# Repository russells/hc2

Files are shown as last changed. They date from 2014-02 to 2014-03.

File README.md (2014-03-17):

# "Hots and Colds thermometer."

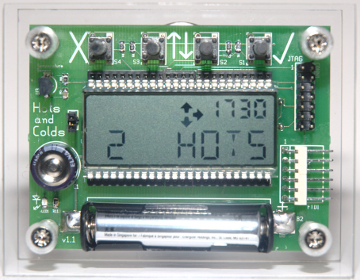
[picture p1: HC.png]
HC


Displays temperature as

 * 20C = "NORMAL"
 * < 20C = "NN COLDS", where NN = 20-T
 * \> 20C = "NN HOTS", where NN = T-20

A wedding present for Andrew and Kate.

# Hardware

## Microcontroller

 * MSP430F449IPZ.
 * Has a builtin LCD controller.
 * http://www.ti.com/product/msp430f449
 * Available from RS.

## Display

### SoftBaugh SBLCDA2

 * Has many display components
    * 14 segment starburst, 7 digits, with 6 decimal points.
    * 7 segment, 4 digits, with 3 decimal points, and colon.
    * Battery meter.
    * Progress bar.
    * Antenna and 3 part signal strength meter.
    * Plus and minus signs.
    * 4 arrow signs.
 * Because of the extra components, more than just having a set of 7 or 14
   segment characters, we can implement a clock and a menu system.
 * Available from http://microcontrollershop.com/

## Temperature sensor

 * MCP9700A
    * Analogue output
    * Vcc down to 2.3V

## Board

 * Made at PCB Zone, http://pcbzone.net/

# Power

 * 2 x AAA cells.

## Power measurements

 * With serial and LED disabled, power consumption has been measured at
   25.8uA mean.
    * 13uA background
    * 60uA, 50us pulses, 3.9ms apart - this is the LCD clock.
    * 430uA, 170 us pulses, at 32Hz (31250us period) - this is the timer
      tick with short periods of 1MHz clock.
    * 510uA, 38ms pulses, at 0.5Hz (2000ms period) - this is the ADC being
      read every two seconds, along with the extra CPU and 1MHz clock
      activity.
    * Total power = 13 + 60\*(50/3900) + 430\*(170/31250) + 510\*(38/2000)
      = 25.8uA
 * With the batteries at 2.9V, one battery was removed.  The unit ran for
   30 minutes, with the capacitor supply voltage dropping to 2.25V.

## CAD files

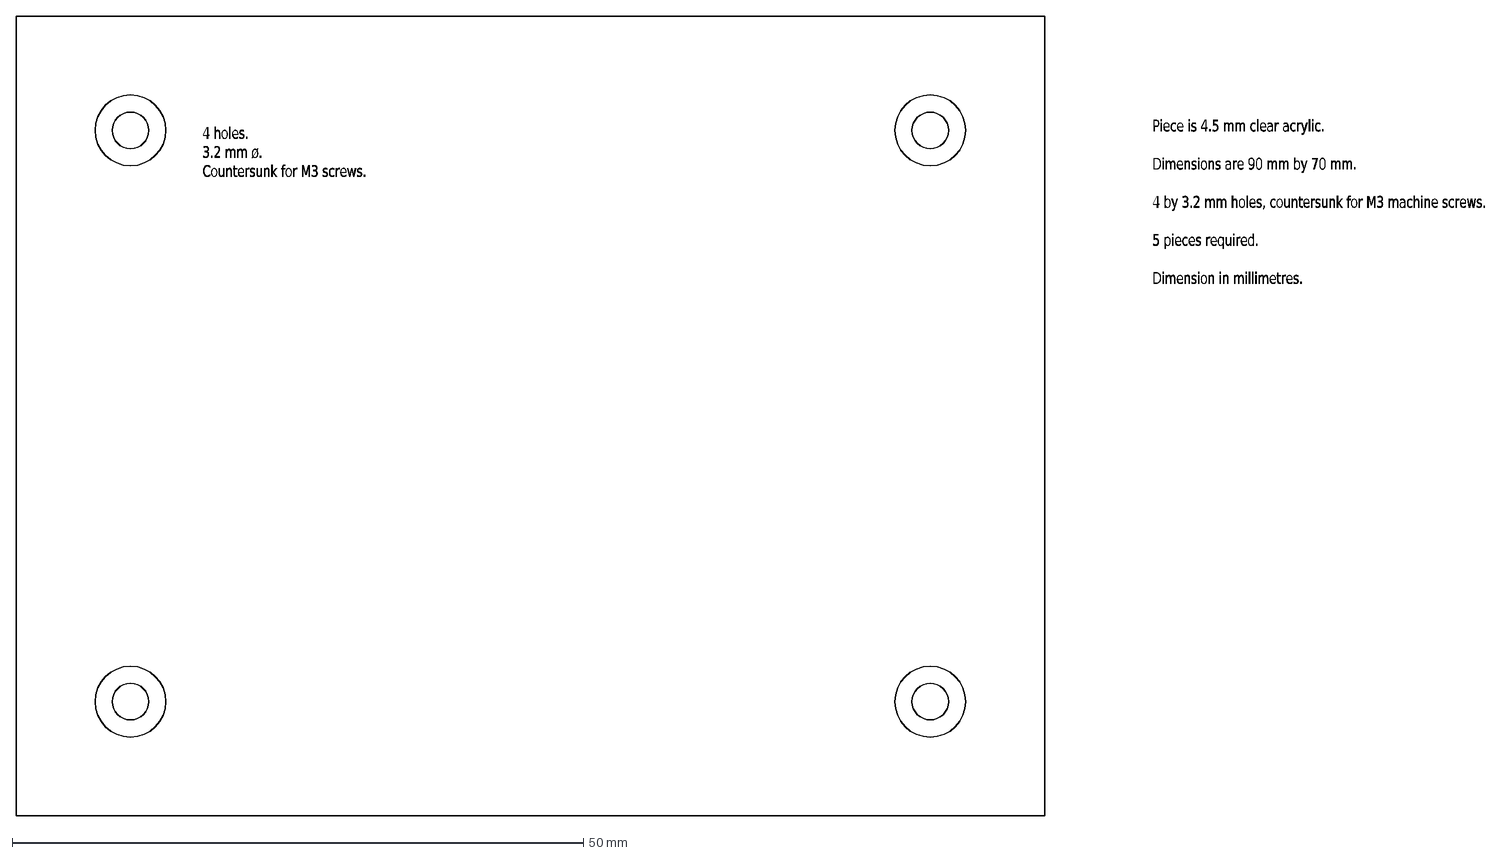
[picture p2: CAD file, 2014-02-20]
panels/back-panel.dxf
Piece is 4.5 mm clear acrylic. Dimensions are 90 mm by 70 mm. 4 by 3.2 mm holes, countersunk for M3 machine screws. 5 pieces required. Dimension in millimetres.
4 holes. 3.2 mm ø. Countersunk for M3 screws.

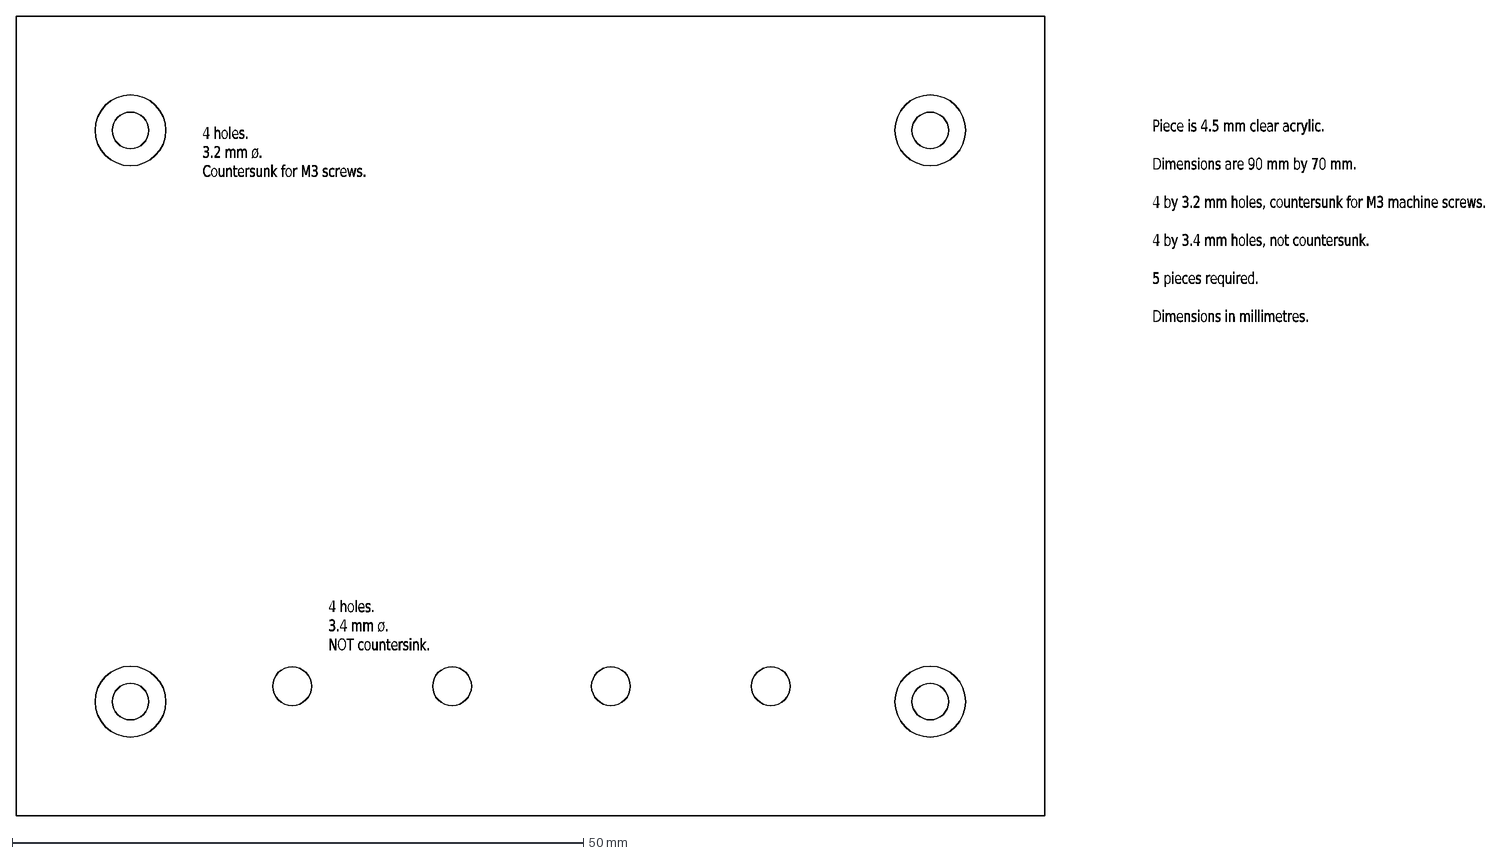
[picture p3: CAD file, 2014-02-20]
panels/front-panel.dxf
4 holes. 3.4 mm ø. NOT countersink.
Piece is 4.5 mm clear acrylic. Dimensions are 90 mm by 70 mm. 4 by 3.2 mm holes, countersunk for M3 machine screws. 4 by 3.4 mm holes, not countersunk. 5 pieces
4 holes. 3.2 mm ø. Countersunk for M3 screws.

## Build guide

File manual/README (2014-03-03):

-*- outline -*-

After running make, these tasks are necessary for the final product:

* When the final manual is produced:

** save manual.pdf as manual-YYYYMMDD.pdf

** Generate manual-book.pdf (make book)

** Save manual-book.pdf as manual-book-YYYYMMDD.pdf

** save dev-card.pdf as dev-card-YYYYMMDD.pdf

** commit these files
*** manual-YYYYMMDD.pdf
*** manual-book-YYYYMMDD.pdf
*** dev-card-YYYYMMDD.pdf

** Print manual-book-YYYYMMDD.pdf on A4 glossy paper.

** Print dev-card-YYYYMMDD.pdf on A5 glossy paper.

** Fold and staple manual-book-YYYYMMDD.pdf

* Calibration info

** Serial number is 1

** Get temperature calibration from a standard

** Set time adjustment with the auto time adjustment checker

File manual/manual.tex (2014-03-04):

\documentclass[11pt]{article}
\usepackage[twoside,inner=2.5cm,outer=1.5cm,paper=a5paper]{geometry}
\usepackage{fixltx2e} % LaTeX patches, \textsubscript
\usepackage{cmap} % fix search and cut-and-paste in Acrobat
\usepackage{ifthen}
\usepackage[T1]{fontenc}
\usepackage[utf8]{inputenc}
\usepackage{graphicx}
\usepackage{longtable,ltcaption,array}
\setlength{\extrarowheight}{2pt}
\newlength{\DUtablewidth} % internal use in tables

\usepackage{mathptmx} % Times
\usepackage[scaled=.90]{helvet}
\usepackage{courier}

%%% User specified packages and stylesheets

%%% Fallback definitions for Docutils-specific commands
% numeric or symbol footnotes with hyperlinks
\providecommand*{\DUfootnotemark}[3]{%
  \raisebox{1em}{\hypertarget{#1}{}}%
  \hyperlink{#2}{\textsuperscript{#3}}%
}
\providecommand{\DUfootnotetext}[4]{%
  \begingroup%
  \renewcommand{\thefootnote}{%
    \protect\raisebox{1em}{\protect\hypertarget{#1}{}}%
    \protect\hyperlink{#2}{#3}}%
  \footnotetext{#4}%
  \endgroup%
}

% hyperlinks:
\ifthenelse{\isundefined{\hypersetup}}{
  \usepackage[colorlinks=true,linkcolor=blue,urlcolor=blue]{hyperref}
  \urlstyle{same} % normal text font (alternatives: tt, rm, sf)
}{}
\hypersetup{
  pdftitle={HOTS AND COLDS Thermometer},
}

%%% Title Data
\title{\phantomsection%
  \textbf{HOTS AND COLDS Thermometer}%
  \label{your-hots-and-colds-thermometer}}
\author{}
\date{}

\pagestyle{plain}
\setlength{\parindent}{0pt}
\setlength{\parskip}{0.3ex}

\newcommand{\HCT}{\textbf{HOTS AND COLDS Thermometer}}

\newcommand{\ButtonEnter}%
           {}
\newcommand{\ButtonCancel}%
           {}
\newcommand{\ButtonUp}%
           {}
\newcommand{\ButtonDown}%
           {}
\newcommand{\ArrowDown}%
           {}
\newcommand{\ArrowLeft}%
           {}
\newcommand{\ArrowRight}%
           {}
\newcommand{\ArrowUp}%
           {}

%%% Body
\begin{document}

\pagestyle{empty}

\setlength{\parindent}{0pt}
\setlength{\parskip}{1ex plus 0.5ex minus 0.5ex}

\begin{center}

  \vfill

  \Huge{\HCT}

  \vfill

  

  %{\small FIXME put in the right picture}

  \vfill

\end{center}

\break

Congratulations on your purchase of a new \HCT{}.

You can now display temperature in your home with the user friendly
\textbf{hots and colds} scale.  This scale is centred on a comfortable
temperature for normal people, which is used as a reference for
temperatures both hotter and colder than that.

Temperatures are displayed as:
\begin{itemize}
\item \texttt{NORMAL} for a normal temperature\footnote{Normal is
  equivalent to 20$^{\textrm{o}}$C}
\item A number of hots for temperatures above \texttt{NORMAL} (eg
  \texttt{12 HOTS})
\item A number of colds for temperatures below \texttt{NORMAL} (eg
  \texttt{3 COLDS})
\end{itemize}
%


\vfill

\break
\tableofcontents

%___________________________________________________________________________

\section*{\phantomsection%
  Setting up%
  \addcontentsline{toc}{section}{Setting up}%
  \label{setting-up}%
}

Remove your \HCT{} from its packaging and either stand it on its base in a
convenient location or use the magnet on its rear to attach it to a
suitable surface (eg your fridge.)

Your \HCT{} has been temperature calibrated and its clock has been set at
the factory.

%___________________________________________________________________________

\section*{\phantomsection%
  Precautions%
  \addcontentsline{toc}{section}{Precautions}%
  \label{precautions}%
}

Your \HCT{} is safe for normal use, but there are some precautions you
should take.
%
\begin{itemize}

\item Exposure to extreme temperatures outside the operating range (see
  Specifications) may result in incorrect operation or failure.  At very
  low temperatures (such as in your freezer) the display will appear to
  change very slowly.

\item Do not get the device wet.  If you put it in your freezer, place it
  in a plastic bag first, and only remove it from the plastic bag when the
  bag and device are back at room temperature.

\item Do not leave in direct sunlight.  This will result in incorrect
  temperature readings.  For outside temperature readings, place the device
  in a Stevenson screen.\footnote{Stevenson screen not supplied.}

\item Not for use where failure could result in injury or death.

\item Not for medical use.

\end{itemize}

\vfill% Push the footnote to the bottom of the page.

%___________________________________________________________________________

\section*{\phantomsection%
  The display%
  \addcontentsline{toc}{section}{The display}%
  \label{the-display}%
}



The display of your \HCT{} shows the current time at the top right, and the
current temperature on the main display at the bottom.  The main display is
also used for the menu system, and to display recorded maximum and minimum
temperatures.

While in the menu system, a timeout showing four bars shows at the top left
of the display.  When the timeout bars disappear after 12 seconds without
button presses, the display will exit the menu system.

Four arrow indicators tell you which buttons are active at any time.
\ArrowUp{} means the up botton (\ButtonUp), \ArrowDown{} means the down
button (\ButtonDown), \ArrowLeft{} means the cancel button (\ButtonCancel),
and \ArrowRight{} means the enter button (\ButtonEnter).

%___________________________________________________________________________

\section*{\phantomsection%
  The buttons%
  \addcontentsline{toc}{section}{The buttons}%
  \label{the-buttons}%
}

Your \HCT{} has four buttons.



\newcounter{listcnt0}
\begin{list}{\arabic{listcnt0}.}
{
\usecounter{listcnt0}
\setlength{\rightmargin}{\leftmargin}
}

\item \ButtonCancel{} is for the cancel function.

\item \ButtonUp{} is for the up function, and to display maximum
  temperature.

\item \ButtonDown{} is for the down function, and to display minimum
  temperature.

\item \ButtonEnter{} is for the enter function, and for starting the menu.

\end{list}

%___________________________________________________________________________

\section*{\phantomsection%
  Configuring%
  \addcontentsline{toc}{section}{Configuring}%
  \label{configuring}%
}

%___________________________________________________________________________

\subsection*{\phantomsection%
  Setting time%
  \addcontentsline{toc}{subsection}{Setting time}%
  \label{setting-time}%
}
%
\begin{itemize}

\item Press \ButtonEnter{}.

\item The display shows \texttt{SETTIME}.

\item Press \ButtonEnter{} again.

\item The display shows \texttt{Yr 2014} (or the current year), and the year
  will flash.

\item Press \ButtonUp{} or \ButtonDown{} to change the year.  You cannot
  set the year to before 2014.

\item Press \ButtonEnter{} to go to month, then to day, then to hour, then
  to minute.  Each time element can be changed with \ButtonUp{} and
  \ButtonDown{}.

\item After you press \ButtonEnter{} when setting the minutes, the time is
  set and saved.

\item You can cancel setting the time with \ButtonCancel{}.

\item If you don't press a button for 12 seconds, the display will exit the
  menu system without setting the time.

\item If power is lost, the default starting date and time is 2014-03-07 at
  17:30.

\end{itemize}

%___________________________________________________________________________

\subsection*{\phantomsection%
  Calibrating temperature%
  \addcontentsline{toc}{subsection}{Calibrating temperature}%
  \label{calibrating-temperature}%
}

Your \HCT{} was calibrated at the factory, so you
should not need to do your own calibration.  But if you wish to change the
calibration:
%
\begin{itemize}

\item Press \ButtonEnter{} to enter the menu.

\item The display shows \texttt{SETTIME}.

\item Press \ButtonDown{}.

\item The display shows \texttt{CALTEMP}.

\item Press \ButtonEnter{}.

\item The display will now show the temperature in the archaic ``degrees
  Celsius'' scale, and an offset.  You can compare the temperature with an
  old style thermometer, and adjust in 0.5\textsuperscript{O}C steps.

\end{itemize}



\begin{itemize}

\item When you are happy with the calibration, press \ButtonEnter{}.

\item The calibration is saved permanently.

\item You can cancel the temperature calibration changes by pressing
  \ButtonCancel{}.

\item If you don't press a button for 12 seconds, the display will exit the
  menu system without saving the new temperature calibration.

\end{itemize}

%___________________________________________________________________________

\subsection*{\phantomsection%
  Adjusting time%
  \addcontentsline{toc}{subsection}{Adjusting time}%
  \label{adjusting-time}%
}

Your \HCT{} was adjusted to keep correct time at the factory, and should
not drift more than a minute per year.  But if you wish to change its time
adjustment:
%
\begin{itemize}

\item Press \ButtonEnter{} to enter the menu.

\item The display says \texttt{SETTIME}.

\item Press \ButtonDown{} twice.

\item The display says \texttt{ADJTIME}.

\item Press \ButtonEnter{}.

\item The display will show the current adjustment in seconds per day.  To
  make the clock run slower, decrease the number (or make it more
  negative.)  To make the clock run faster, increase the number (or make it
  less negative.)

\item You can change the adjustment from $-20$ seconds per day to $+20$
  seconds per day, in steps of 0.25 seconds per day.

\item When you are happy with the adjustment, press \ButtonEnter{}.

\item The time adjustment is saved permanently.

\item You can cancel the time adjustment changes by pressing
  \ButtonCancel{}.

\item If you don't press a button for 12 seconds, the display will exit the
  menu system without saving the new time adjustment.

\end{itemize}

%___________________________________________________________________________

\section*{\phantomsection%
  Displaying the maximum or minimum temperature%
  \addcontentsline{toc}{section}{Displaying the maximum or minimum temperature}%
  \label{displaying-the-maximum-or-minimum-temperature}%
}

When your \HCT{} is displaying the current temperature, you can press
\ButtonUp{} to display the maximum temperature since the last 3pm time.  It
will also display the maximum temperature in the 24 hours to the last 3pm
time, then return to displaying the current temperature.

Press \ButtonDown{} while the display is showing the current temperature,
or while displaying the maximum, to display the minimum temperature since
the last 9am time, followed by the minimum temperature in the 24 hours up
to the last 9am time.

The times and temperatures are shown sequentially, as they don't fit on the
display together.  For example:

\begin{center}









\end{center}

%___________________________________________________________________________

\section*{\phantomsection%
  Changing the battery%
  \addcontentsline{toc}{section}{Changing the battery}%
  \label{changing-the-battery}%
}

Your \HCT{} requires two 1.5V AAA size batteries.  When the display goes
dim, the batteries should be changed.

To change the batteries, use a pozidrive screwdriver to remove the front
and rear covers.  There is one battery under the front cover and one under
the rear cover.  If the old batteries were not too flat, your \HCT{} will
continue to run for a few minutes while you insert new batteries.

High capacity lithium batteries should last for at least three years in
normal use.

%___________________________________________________________________________
\break

\section*{\phantomsection%
  Specifications%
  \addcontentsline{toc}{section}{Specifications}%
  \label{specifications}%
}

\setlength{\DUtablewidth}{\linewidth}
\begin{longtable*}[c]{|p{0.450\DUtablewidth}|p{0.450\DUtablewidth}|}
\hline

Minimum temperature & 50 COLDS \\
\hline

Maximum temperature & 50 HOTS \\
\hline

Temperature calibration range &
$\pm 4.5$ HOTS/COLDS ($\pm 4.5$$^{\textrm{o}}$C --- Eww) \\
\hline

Time accuracy (with adjustment) &
$\pm 0.125$ seconds per day (about 45 seconds per year) \\
\hline

Time adjustment range & $\pm 20$ seconds per day \\
\hline

Battery life & At least 3 years, with lithium AAA batteries \\

\hline

\end{longtable*}

%___________________________________________________________________________

\section*{\phantomsection%
  Warranty%
  \addcontentsline{toc}{section}{Warranty}%
  \label{warranty}%
}

Your \HCT{} has a lifetime warranty.  When it stops working, it is at the
end of its life.

In order to fix identified issues with the device, we may at times offer
software upgrades.

%___________________________________________________________________________
\break

\section*{\phantomsection%
  Calibration Information%
  \addcontentsline{toc}{section}{Calibration Information}%
  \label{calibration-information}%
}
%
\begin{longtable*}[c]{|p{0.450\DUtablewidth}|p{0.450\DUtablewidth}|}
\hline
\texttt{Serial number} & \vskip 2.5em \\
\hline
\texttt{Temperature calibration} & \vskip 2.5em \\
\hline
\texttt{Time adjustment} & \vskip 2.5em \\
\hline
\texttt{Calibrated by} & \vskip 2.5em \\
\hline
\end{longtable*}

\end{document}

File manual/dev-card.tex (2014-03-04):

\documentclass[12pt]{article}
\usepackage[left=1cm,right=1cm,top=1cm,bottom=1cm,paper=a5paper]{geometry}
% generated by Docutils <http://docutils.sourceforge.net/>
\usepackage{fixltx2e} % LaTeX patches, \textsubscript
\usepackage{cmap} % fix search and cut-and-paste in Acrobat
\usepackage{ifthen}
\usepackage[T1]{fontenc}
\usepackage[utf8]{inputenc}
\usepackage{graphicx}
\usepackage{color}
\definecolor{devbackground}{RGB}{201,176,132}

%%% Custom LaTeX preamble
% PDF Standard Fonts
\usepackage{mathptmx} % Times
\usepackage[scaled=.90]{helvet}
\usepackage{courier}

%%% User specified packages and stylesheets

%%% Make the footnote line cross the whole page.
\renewcommand{\footnoterule}{%
  \kern -3pt
  \hrule width \textwidth height 1pt
  \kern 2pt
}

%%% Fallback definitions for Docutils-specific commands
% numeric or symbol footnotes with hyperlinks
\providecommand*{\DUfootnotemark}[3]{%
  \raisebox{1em}{\hypertarget{#1}{}}%
  \hyperlink{#2}{\textsuperscript{#3}}%
}
\providecommand{\DUfootnotetext}[4]{%
  \begingroup%
  \renewcommand{\thefootnote}{%
    \protect\raisebox{1em}{\protect\hypertarget{#1}{}}%
    \protect\hyperlink{#2}{#3}}%
  \footnotetext{#4}%
  \endgroup%
}

% hyperlinks:
\ifthenelse{\isundefined{\hypersetup}}{
  \usepackage[colorlinks=true,linkcolor=blue,urlcolor=blue]{hyperref}
  \urlstyle{same} % normal text font (alternatives: tt, rm, sf)
}{}
\hypersetup{
  pdftitle={Developers!},
}

%%% Title Data
\title{\phantomsection%
  Developers!\DUfootnotemark{id1}{id2}{1}%
  \label{developers-1}}
\author{}
\date{}

\newcommand{\HCT}{\textbf{HOTS AND COLDS Thermometer}}

%%% Body
\begin{document}
\pagestyle{empty}

\setlength{\parindent}{0pt}
\setlength{\parskip}{3ex plus 0.5ex minus 0.5ex}

\pagecolor{devbackground}

%\maketitle
%
%~
%\vskip 1ex
\begin{center}
  \Huge{Developers!}
\end{center}

\begin{center}
{\large Do you have a \HCT{}?}

{\large Would you like to help us make it even better?}

{\large Join us at {\Large\url{http://bitbucket.org/russells/hc2}}}
\end{center}
%
\DUfootnotetext{id2}{id1}{}{\center ``Developers, developers, developers,
  developers!''\\ }

\begin{center}
  % 824 by 476: 0.5777 (0.9. 0.51990)
  
\end{center}
%
\begin{center}
{\large For a limited time all new \HCT{} owners will be automatically
  invited to the developers group.}
\end{center}
%
\vfill
%
\begin{center}
  
\end{center}
%
\begin{center}
  % 496 by 341: 0.6875 (0.9, 0.61875)
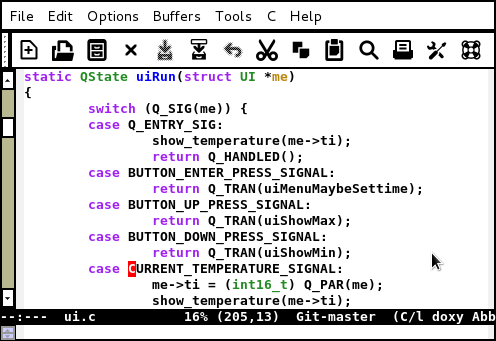
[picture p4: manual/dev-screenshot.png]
  
\end{center}

\end{document}

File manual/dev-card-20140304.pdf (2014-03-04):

## Developers!

Do you have a HOTS AND COLDS Thermometer?

Would you like to help us make it even better?

### Join us at http://bitbucket.org/russells/hc2

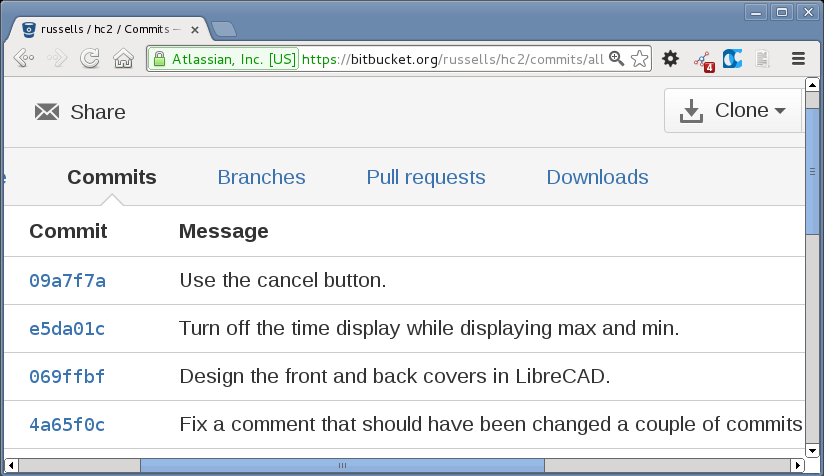
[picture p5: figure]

For a limited time all new HOTS AND COLDS Thermometer owners will be automatically invited to the developers group.

“Developers, developers, developers, developers!”

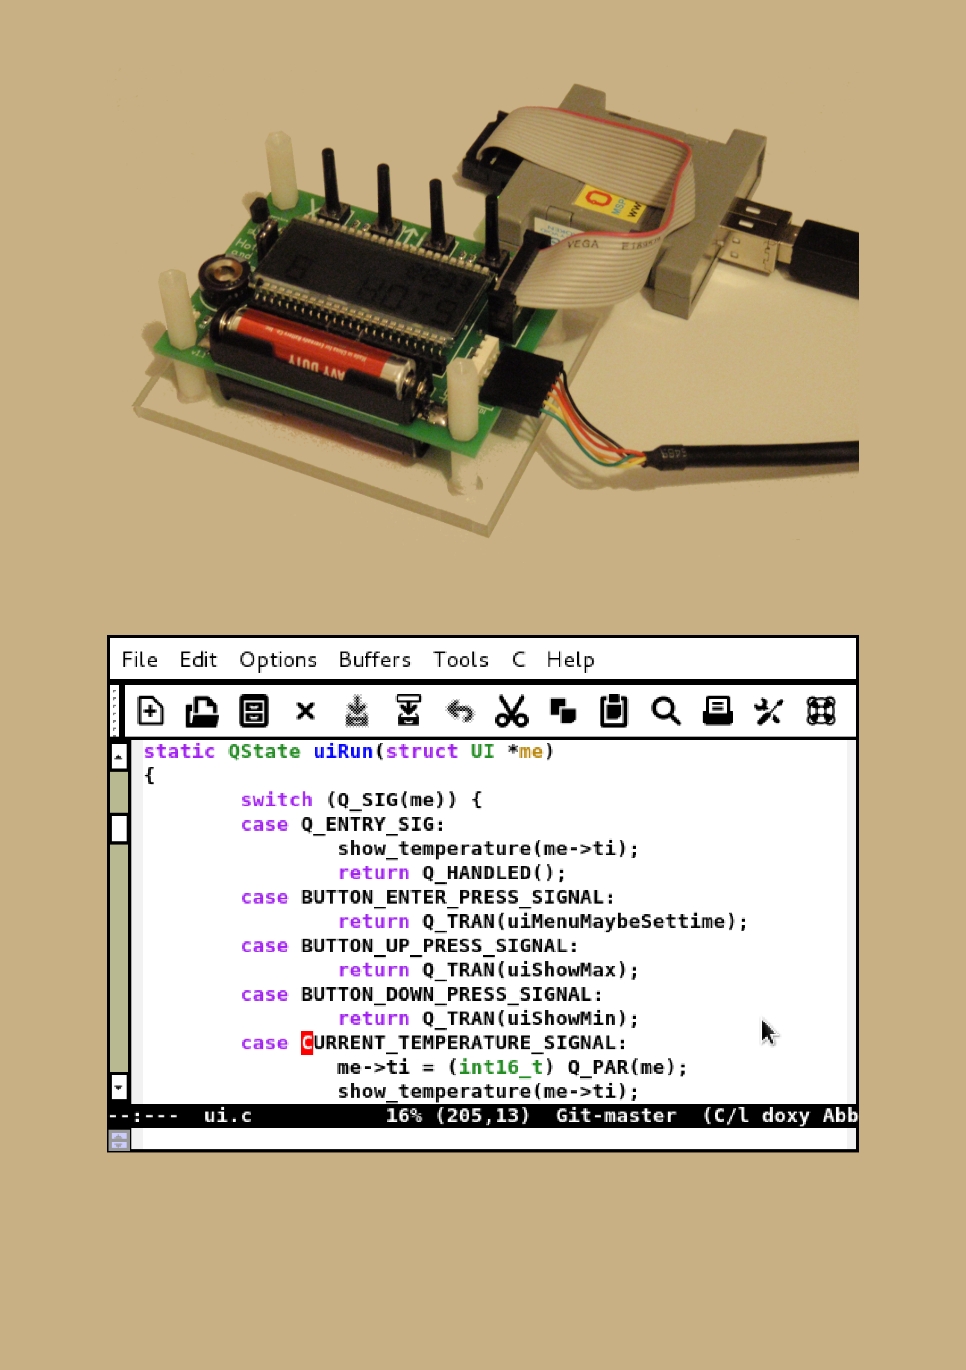
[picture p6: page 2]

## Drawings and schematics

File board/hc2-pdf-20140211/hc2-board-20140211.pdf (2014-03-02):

# hc-board.pcb

# 1. Table of Contents (This Page) Created on Sun Mar 2 13:35:01 2014

# 2. component 3. solder 4. plated-drill 5. componentmask 6. soldermask 7. topsilk 8. bottomsilk 9. toppaste 10. bottompaste 11. topassembly 12. bottomassembly 13. fab

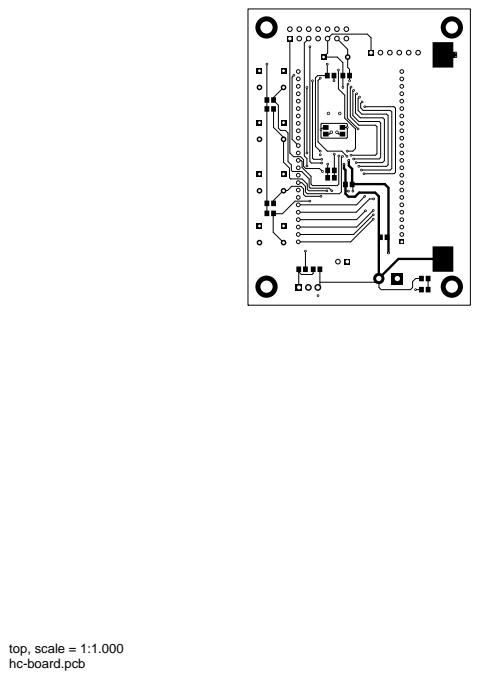
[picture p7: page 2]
top, scale = 1:1.000

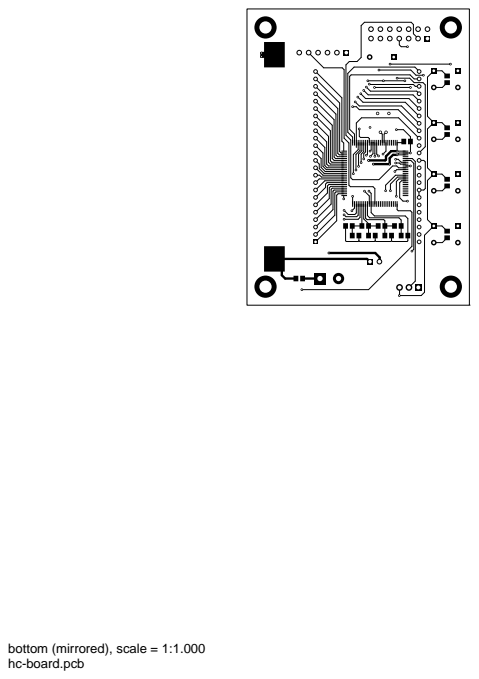
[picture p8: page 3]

bottom (mirrored), scale = 1:1.000

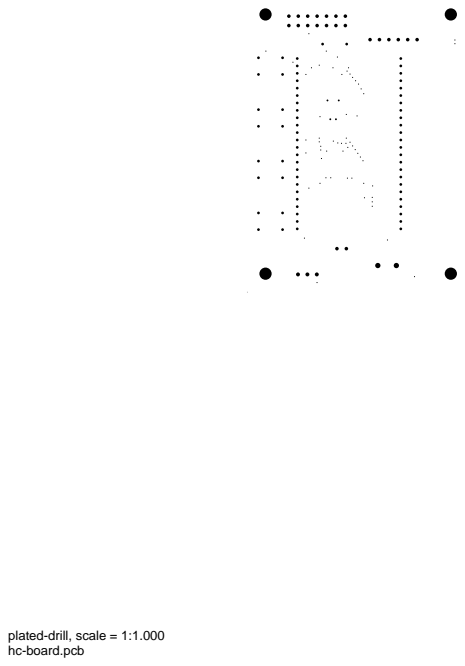
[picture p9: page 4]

plated-drill, scale = 1:1.000

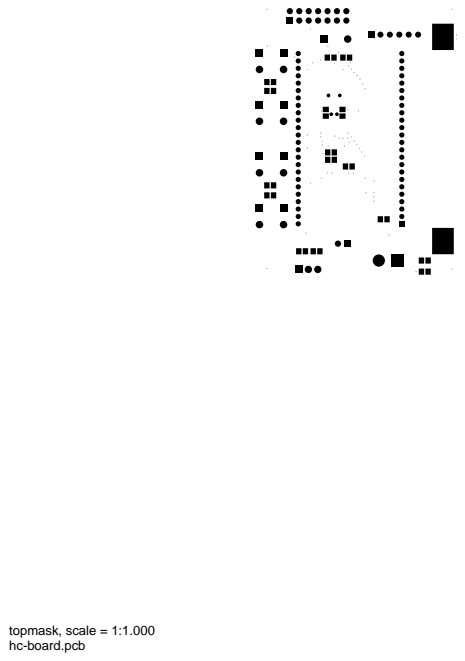
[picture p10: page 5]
topmask, scale = 1:1.000

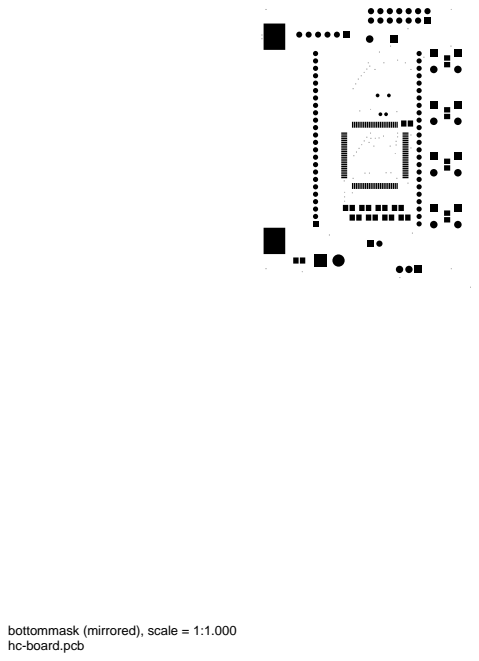
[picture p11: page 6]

bottommask (mirrored), scale = 1:1.000

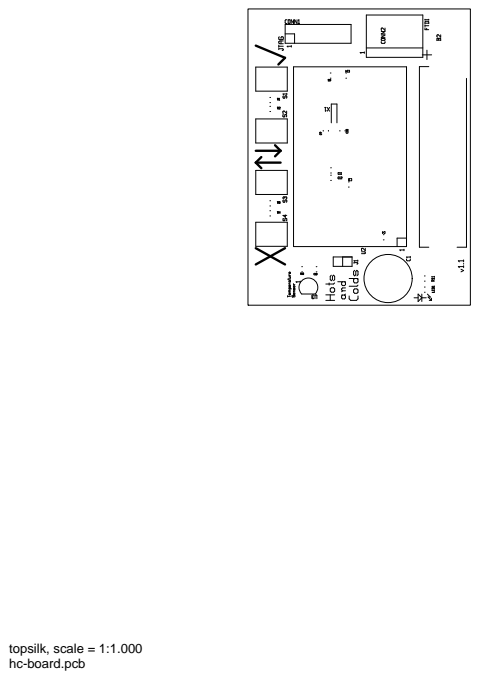
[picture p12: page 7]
topsilk, scale = 1:1.000

bottomsilk (mirrored), scale = 1:1.000

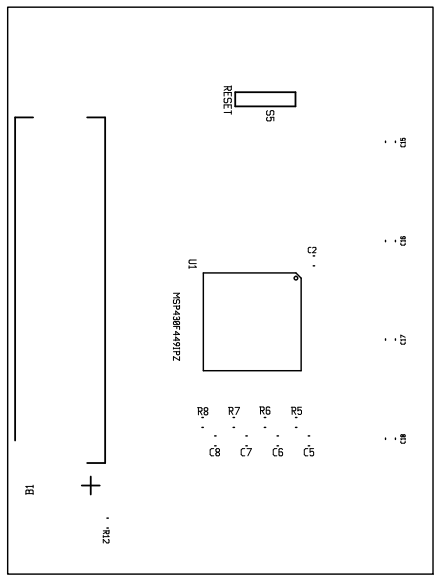
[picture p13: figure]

toppaste, scale = 1:1.000 bottompaste (mirrored), scale = 1:1.000

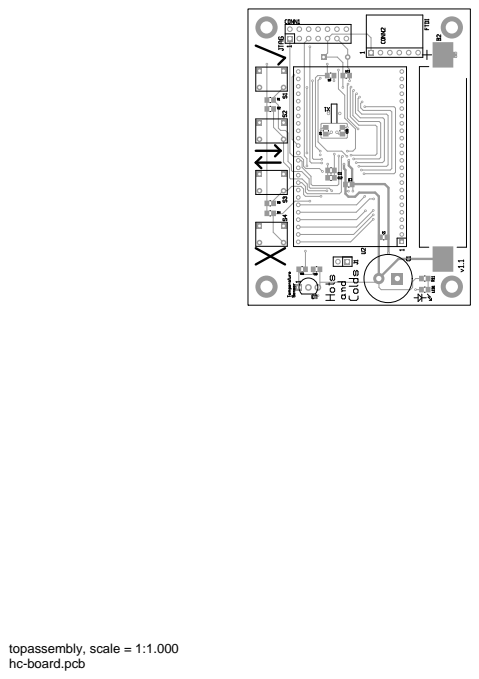
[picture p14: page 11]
topassembly, scale = 1:1.000

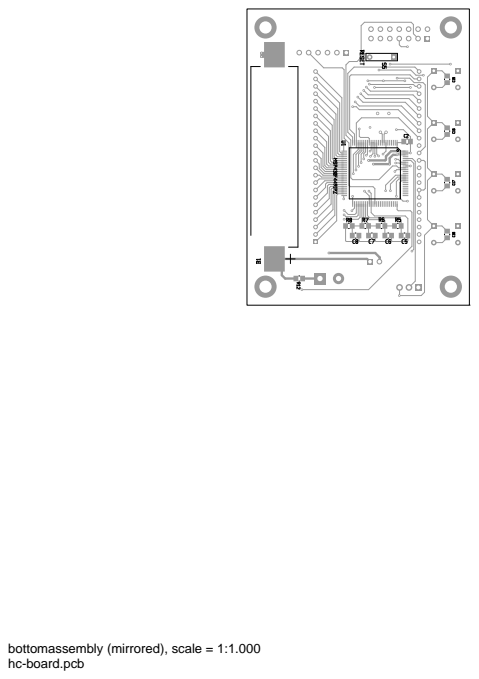
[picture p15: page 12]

bottomassembly (mirrored), scale = 1:1.000

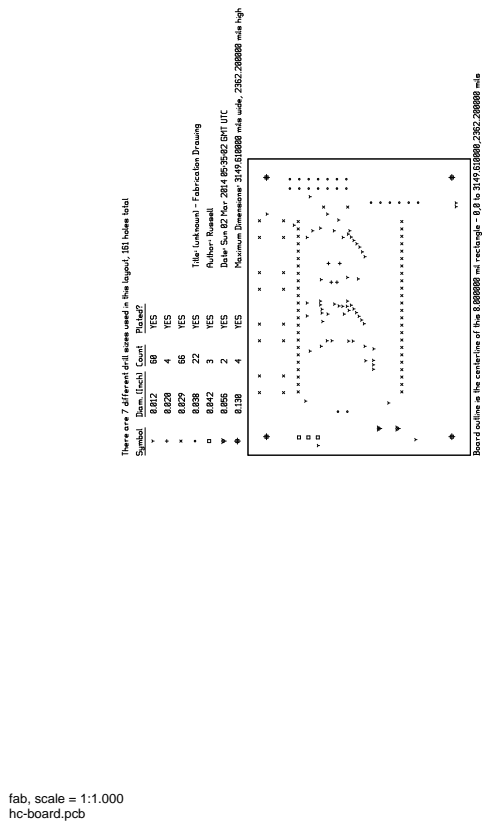
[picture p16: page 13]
fab, scale = 1:1.000

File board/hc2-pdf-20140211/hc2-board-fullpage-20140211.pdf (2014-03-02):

# hc-board.pcb

# 1. Table of Contents (This Page) Created on Sun Mar 2 13:38:17 2014

# 2. component 3. solder 4. plated-drill 5. componentmask 6. soldermask 7. topsilk 8. bottomsilk 9. toppaste 10. bottompaste 11. topassembly 12. bottomassembly 13. fab

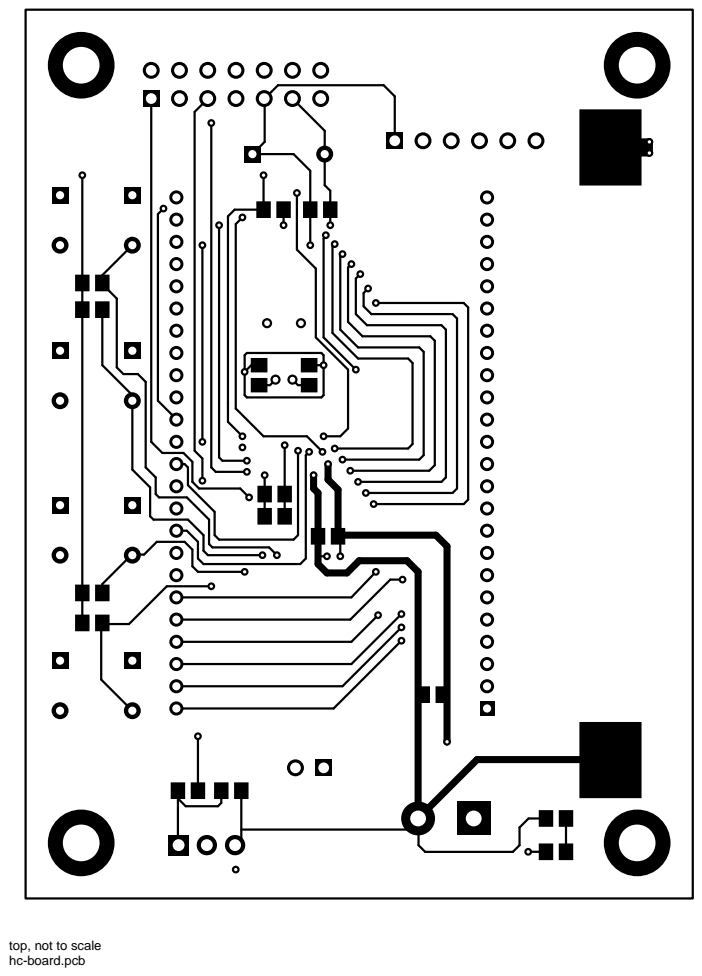
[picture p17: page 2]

top, not to scale

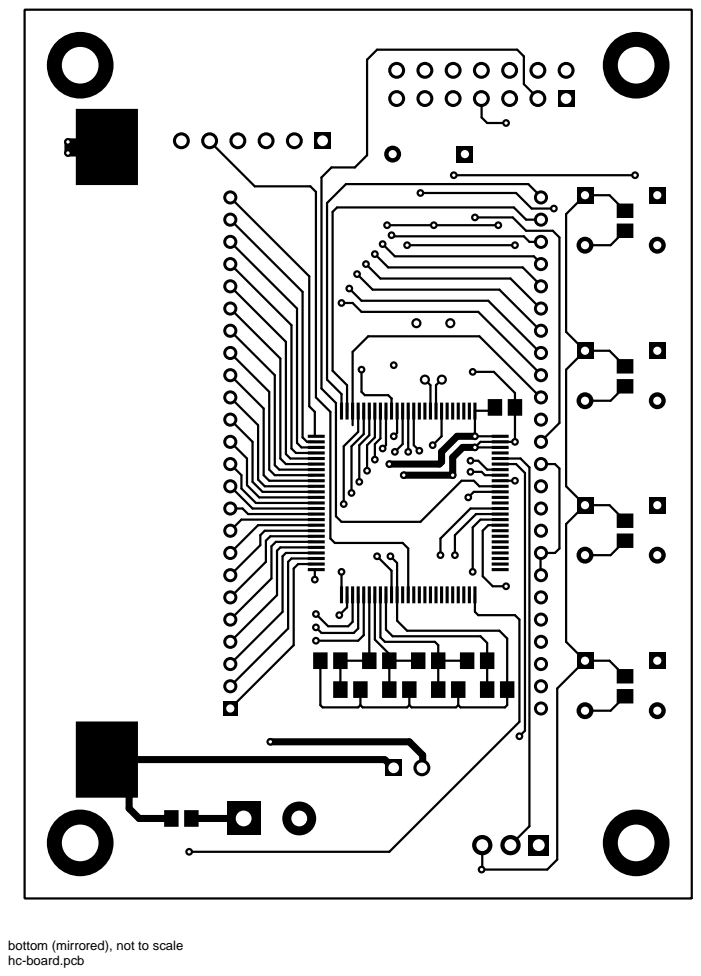
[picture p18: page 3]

bottom (mirrored), not to scale


plated-drill, not to scale


topmask, not to scale


bottommask (mirrored), not to scale


topsilk, not to scale


bottomsilk (mirrored), not to scale

toppaste, not to scale bottompaste (mirrored), not to scale


topassembly, not to scale


bottomassembly (mirrored), not to scale


fab, not to scale

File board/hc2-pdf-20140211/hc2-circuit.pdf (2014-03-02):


C1 is intended to allow
battery changes without
losing time.

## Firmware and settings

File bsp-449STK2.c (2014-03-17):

#include "bsp.h"
#include "hc.h"
#include "ui.h"
#include "recorder.h"
#include "buttons.h"
#include "qpn_port.h"
#include "morse.h"
#include "serial.h"
#include <msp430.h>
#include <stdlib.h>
#include <string.h>
#include <stdio.h>
#include "truefalse.h"


Q_DEFINE_THIS_MODULE("BSP");


#include "bsp-449STK2.h"


#define SB(_port,_bit) do { (_port) |=   (_bit);  } while(0)
#define CB(_port,_bit) do { (_port) &= (~(_bit)); } while(0)


#define TEMPPOWER_OUT P6OUT
#define TEMPPOWER_DIR P6DIR
#define TEMPPOWER_SEL P6SEL
#define TEMPPOWER_BIT BIT0

#define TEMPERATURE_OUT P6OUT
#define TEMPERATURE_DIR P6DIR
#define TEMPERATURE_SEL P6SEL
#define TEMPERATURE_BIT BIT1

#define LED_OUT P2OUT
#define LED_DIR P2DIR
#define LED_SEL P2SEL
#define LED_BIT BIT4

/** Select the temperature analogue input channel. */
#define TEMPERATURE_INCH 0b0001
#define VCC_INCH         0b1011


/** If true, we want QP fast timer 1 running. */
static volatile uint8_t fast_timer_1 = 0;


/** If true, we want QP fast timer 2 running. */
static volatile uint8_t fast_timer_2 = 0;


static struct AssertionBuffer *assertion_buffer;


void Q_onAssert(char const Q_ROM * const Q_ROM_VAR file, int line)
{
	BSP_stop_everything();
	assertion_buffer->valid[0] = '\0';
	assertion_buffer->valid[1] = '\0';
	assertion_buffer->line = line;
	strncpy(assertion_buffer->msg, file, ASSERTION_BUFFER_MSG_SIZE);
	assertion_buffer->msg[ASSERTION_BUFFER_MSG_SIZE - 1] = '\0';
	assertion_buffer->valid[0] = 'A';
	assertion_buffer->valid[1] = 'B';
	serial_drain();
	serial_send("ASSERT: ");
	serial_send(file);
	serial_send_char(':');
	serial_send_int(line);
	serial_send("\r\n");
	serial_drain();
	morse_assert(file,line);
}


/** Initialise the basic timer but don't turn on its interrupt. */
static void
basic_timer1_init(void)
{
	/* Interrupt at 0.5Hz.  BTSSEL=0 (clock source is ACLK at 32768Hz),
	   BTDIV=1 (fCLK2 = ACLK/256), BTIPx=111 (interrupt at fCLK2/256).
	   (32768/256)/256 = 0.5.  */
	BTCTL = (BTSSEL & 0) |
		(BTHOLD & 0) |
		BTDIV |
		/* fCLK2/4 == 32Hz */
		(BTIP2 * 0) | (BTIP1 & 0) | BTIP0;
}


/**
 * Turn the first fast timer on or off.
 *
 * We count up at turn on requests and down on turn off requests.  We turn off
 * the timer when the count gets to zero.  We don't decrement the counter below
 * zero.  All callers should have balanced on and off calls, but there is a
 * chance that a caller will not, and we may mask that behaviour with the
 * counter.
 *
 * @param onoff if true, the caller wants the first fast timer on.  Otherwise
 * the caller wants the first fast timer off.
 */
void BSP_fast_timer_1(uint8_t onoff)
{
	if (onoff) {
		fast_timer_1 ++;
	} else if (fast_timer_1) {
		fast_timer_1 --;
	}
}


/**
 * Turn the second fast timer on or off.
 *
 * @see BSP_fast_timer_1()
 */
void BSP_fast_timer_2(uint8_t onoff)
{
	if (onoff) {
		fast_timer_2 ++;
	} else if (fast_timer_2) {
		fast_timer_2 --;
	}
}


static void temperature_input_init(void)
{

	/* Ensure the temperature power pin is output as low before we enable
	   it, so we don't get a transient power supply on the chip. */
	CB(TEMPPOWER_OUT, TEMPPOWER_BIT);
	SB(TEMPPOWER_DIR, TEMPPOWER_BIT);
	CB(TEMPPOWER_SEL, TEMPPOWER_BIT); /* IO function. */
	/* Set the temperature analogue as a digital input for now, and only
	   change it to ADC input when required. */
	CB(TEMPERATURE_OUT, TEMPERATURE_BIT);
	CB(TEMPERATURE_DIR, TEMPERATURE_BIT);
	CB(TEMPERATURE_SEL, TEMPERATURE_BIT); /* IO function. */
}


void BSP_init(void)
{
	uint8_t fll_ctl0;

	WDTCTL = WDTPW | WDTHOLD; /* Stop the watchdog */

	FLL_CTL0 &= ~XTS_FLL;	/* XT1 as low-frequency */
	/* Turn on the internal oscillator capacitors.  XCAP18PF is both the
	   XCAPxPF bits on, so use that as a mask for the required bits. */
	fll_ctl0 = FLL_CTL0;
	fll_ctl0 &= ~XCAP18PF;
	fll_ctl0 |= XCAP18PF;
	FLL_CTL0 = fll_ctl0;
	_BIC_SR(OSCOFF);	/* turn on XT1 oscillator */

	do {			/* wait in loop until crystal is stable */
		IFG1 &= ~OFIFG;
	} while (IFG1 & OFIFG);

	// Interrupts on.
	_BIS_SR(GIE);

	basic_timer1_init();

	temperature_input_init();

#ifdef LED
	SB(LED_DIR, LED_BIT);
	BSP_led_off();

	/* Wait at start so we can see resets. */
	BSP_led_on();
	__delay_cycles(1000000L);
	BSP_led_off();
	__delay_cycles(1000000L);
#endif

	/* Buttons are on P1.0 to P1.3. */
	/* Input */
	CB(P1DIR, BIT0);
	CB(P1DIR, BIT1);
	CB(P1DIR, BIT2);
	CB(P1DIR, BIT3);

	/* Set the direction and output bits appropriately for an unused port
	   pin. */
#define UNUSED(port_,bit_)				\
	do {						\
		/* Set to output. */			\
		SB( P ## port_ ## DIR, BIT ## bit_ );	\
		/* Set output low. */			\
		CB( P ## port_ ## OUT, BIT ## bit_ );	\
	} while (0)

	/* Make all the unused pins output zero.  We could set all the bits in
	   each port at once, but this only happens once and doesn't take that
	   long, so it's not an efficiency concern.  Separating them out like
	   this allows us to easily change one pin if it's needed later. */
	UNUSED(1,4);
	UNUSED(1,5);
	UNUSED(1,6);
	UNUSED(1,7);

	UNUSED(2,0);
	UNUSED(2,1);
	UNUSED(2,2);
	UNUSED(2,3);
	//UNUSED(2,4); // LED
	UNUSED(2,5);
	UNUSED(2,6);
	UNUSED(2,7);

	UNUSED(3,0);
	UNUSED(3,1);
	UNUSED(3,2);
	UNUSED(3,3);
	UNUSED(3,4);
	UNUSED(3,5);
	UNUSED(3,6);
	UNUSED(3,7);

	UNUSED(4,1);

	UNUSED(6,2);
	UNUSED(6,3);
	UNUSED(6,4);
	UNUSED(6,5);
	UNUSED(6,6);
	UNUSED(6,7);
}


void QF_onStartup(void)
{
	// Turn on the basic timer interrupt.
	IE2 |= BTIE;
}


void QF_onIdle(void)
{
	BSP_led_off();
#ifdef SERIAL
	/* If we're running the serial port (for debugging) don't stop SMCLK.
	   SMCLK keeps running while the CPU is running, and we don't shutdown
	   the CPU. */
	__enable_interrupt();
#else
	ENTER_LPM();
#endif
}


#ifdef LED
/**
 * Turn on the monitoring LED.
 *
 * The LED is also used for morse code assertions.
 */
void BSP_led_on(void)
{
	SB(LED_OUT, LED_BIT);
}


/**
 * Turn off the monitoring LED.
 *
 * @see BSP_led_on()
 */
void BSP_led_off(void)
{
	CB(LED_OUT, LED_BIT);
}
#endif


/**
 * Tell the timer ISR to add or subtract an certain number of ticks.
 *
 * The ticks will normally equal zero or plus/minus an eighth of a second.
 *
 * This number is added to the ISR counter when it passes the middle of the
 * count, to avoid any wrapping or over/underflow issues.
 */
static volatile int8_t counter_adjustment = 0;


/**
 * Advance the tick counter to make the second that much shorter.
 *
 * This speeds up (advances) the clock.
 */
void BSP_add_8th_second(void)
{
	Q_ASSERT( ! counter_adjustment );
	__disable_interrupt();
	counter_adjustment = 4;
	__enable_interrupt();
}


/**
 * Retard the tick counter to make the second that much longer.
 *
 * This slows down (retards) the clock.
 */
void BSP_sub_8th_second(void)
{
	Q_ASSERT( ! counter_adjustment );
	__disable_interrupt();
	counter_adjustment = -4;
	__enable_interrupt();
}


static inline uint8_t BSP_button_1(void) { return ! (P1IN & BIT0); }


static inline uint8_t BSP_button_2(void) { return ! (P1IN & BIT1); }
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

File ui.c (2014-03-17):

#include "ui.h"
#include "hc.h"
#include "bsp.h"
#include "serial.h"
#include "lcd.h"
#include "rtc.h"
#include "buttons.h"
#include "time.h"
#include "titime.h"
#include "recorder.h"
#include <string.h>
#include <stdio.h>		/* For snprintf() */
/* Contains declarations of temperature sensing ranges: MINTI, MAXTI,
   NCONVERSIONS. */
#include "bsp-temperature-scale.h"

#include "truefalse.h"


Q_DEFINE_THIS_MODULE("UI");


static QState uiInitial(struct UI *me);
static QState uiTop(struct UI *me);

static QState scroll(struct UI *me);
static QState scrollText(struct UI *me);

static QState uiRun(struct UI *me);

static QState uiMenu(struct UI *me);

static QState uiShowMaxOrMin(struct UI *me);
static QState uiShowMaxTop(struct UI *me);
static QState uiShowMax(struct UI *me);
static QState uiShowMinTop(struct UI *me);
static QState uiShowMin(struct UI *me);

static QState uiMenuMaybeSettime(struct UI *me);
static QState uiMenuSettimeYears(struct UI *me);
static QState uiMenuSettimeYearsFlash(struct UI *me);
static QState uiMenuSettimeMonths(struct UI *me);
static QState uiMenuSettimeMonthsFlash(struct UI *me);
static QState uiMenuSettimeDaysCheckmax(struct UI *me);
static QState uiMenuSettimeDays(struct UI *me);
static QState uiMenuSettimeDaysFlash(struct UI *me);
static QState uiMenuSettimeHours(struct UI *me);
static QState uiMenuSettimeHoursFlash(struct UI *me);
static QState uiMenuSettimeMinutes(struct UI *me);
static QState uiMenuSettimeMinutesFlash(struct UI *me);

static QState uiMenuMaybeCalibrate(struct UI *me);
static QState uiMenuCalibrate(struct UI *me);
static QState uiMenuCalibratePause(struct UI *me);
static QState uiMenuCalibrateDeferExit(struct UI *me);
static QState uiMenuCalibrateTemperatureStart(struct UI *me);
static QState uiMenuCalibrateTemperatureStarted(struct UI *me);
static QState uiMenuCalibrateGetTemperature(struct UI *me);

static QState uiMenuMaybeAdjusttime(struct UI *me);
static QState uiMenuAdjusttime(struct UI *me);

static QState uiMenuShowAssertion(struct UI *me);

static void show_temperature(int16_t t);
static void show_temperature_cal(struct UI *me);


/**
 * The startup banner message.
 *
 * Starts with seven spaces so the strings scrolls across starting at the
 * right.  This avoids special case handling of the beginning of the string.
 */
static const char banner[] = "       \"HOTS AND COLDS\" - FOR ANDREW AND KATE";


struct UI ui;


void ui_ctor(void)
{
	QActive_ctor((QActive*)(&ui), (QStateHandler)(&uiInitial));
	ui.ti = INVALIDTI;
	ui.cal = get_calibration();
	ui.deferredSignal = 0;
	ui.deferredParam = 0;
}


static void defer(struct UI *me)
{
	me->deferredSignal = Q_SIG(me);
	me->deferredParam = Q_PAR(me);
}


static void recall(struct UI *me)
{
	if (me->deferredSignal) {
		QActive_post(&me->super, me->deferredSignal, me->deferredParam);
		me->deferredSignal = 0;
		me->deferredParam = 0;
	}
}


static QState uiInitial(struct UI *me)
{
	return Q_TRAN(scrollText);
}


static void show_time(const struct Time *time)
{
	/** Hack alert!  This code rashly assumes that the ht, h1, mt, and m1
	    fields contain ASCII digits, and that they are consecutive in
	    memory.  This code broke when I added the year, month, and day
	    fields to struct Time, because it previously assumed that &time was
	    the same as &(time->ht). */
	lcd_showdigits((const char *)(&(time->ht)));
	if (time->seconds & 0x02) {
		lcd_colon(1);
	} else {
		lcd_colon(0);
	}
}


static QState uiTop(struct UI *me)
{
	const struct Time *time;

	switch (Q_SIG(me)) {
	case Q_ENTRY_SIG:
		lcd_clear();
		lcd_showdigits("6789");
		break;
	case WATCHDOG_SIGNAL:
		// TODO: watchdog reset
		return Q_HANDLED();
	case TEMPERATURE_SIGNAL:
		SERIALSTR("uiTop: TS\r\n");
		return Q_HANDLED();
	case TIME_SIGNAL:
		time = (const struct Time*)(Q_PAR(me));
		Q_ASSERT( time->ht >= '0' && time->ht <= '9' );
		Q_ASSERT( time->h1 >= '0' && time->h1 <= '9' );
		Q_ASSERT( time->mt >= '0' && time->mt <= '9' );
		Q_ASSERT( time->m1 >= '0' && time->m1 <= '9' );
		show_time(time);
		return Q_HANDLED();
	case CURRENT_TEMPERATURE_SIGNAL:
		/* Handle this signal here, so that no matter where the UI is,
		   the current temperature will be available when it's
		   finished. */
		me->ti = (int16_t) Q_PAR(me);
		return Q_HANDLED();
	case BUTTON_CANCEL_PRESS_SIGNAL:
		return Q_TRAN(uiRun);
	}
	return Q_SUPER(QHsm_top);
}


static QState scroll(struct UI *me)
{
	switch (Q_SIG(me)) {
	case Q_ENTRY_SIG:
		SERIALSTR("scroll");
		me->scrollstring = banner;
		me->scrollindex = 0;
		BSP_fast_timer_1(TRUE);
		return Q_HANDLED();
	case BUTTON_ENTER_PRESS_SIGNAL:
	case BUTTON_ENTER_LONG_PRESS_SIGNAL:
	case BUTTON_ENTER_REPEAT_SIGNAL:
	case BUTTON_UP_PRESS_SIGNAL:
	case BUTTON_UP_LONG_PRESS_SIGNAL:
	case BUTTON_UP_REPEAT_SIGNAL:
	case BUTTON_DOWN_PRESS_SIGNAL:
	case BUTTON_DOWN_LONG_PRESS_SIGNAL:
	case BUTTON_DOWN_REPEAT_SIGNAL:
	case BUTTON_CANCEL_PRESS_SIGNAL:
	case BUTTON_CANCEL_LONG_PRESS_SIGNAL:
	case BUTTON_CANCEL_REPEAT_SIGNAL:
		return Q_TRAN(uiRun);
	case Q_EXIT_SIG:
		BSP_fast_timer_1(FALSE);
		/* If we exit here on a button press, the buttons AO (or the
		   Basic Timer 1 ISR) may see the button down immediately, with
		   the result that the UI immediately enters the menu.  Avoid
		   that by telling the buttons to wait. */
		post(&buttons.super, BUTTONS_WAIT_SIGNAL, 0);
		return Q_HANDLED();
	}
	return Q_SUPER(uiTop);
}


static QState scrollText(struct UI *me)
{
	switch (Q_SIG(me)) {
	case Q_ENTRY_SIG:
		strncpy(me->scrolltext, me->scrollstring+me->scrollindex, 7);
		me->scrolltext[7] = '\0';
		lcd_showstring(me->scrolltext);
		QActive_armX((QActive*)me, 1, 15);
		return Q_HANDLED();
	case Q_TIMEOUT1_SIG:
		me->scrollindex ++;
		if (me->scrollstring[me->scrollindex]) {
			return Q_TRAN(scrollText);
		} else {
			return Q_TRAN(uiRun);
		}
	}
	return Q_SUPER(scroll);
}


static QState uiRun(struct UI *me)
{
	switch (Q_SIG(me)) {
	case Q_ENTRY_SIG:
		lcd_buttons(LCD_BUTTONS_ENTER_UP_DOWN);
		show_temperature(me->ti);
		show_time(gettimep());
		return Q_HANDLED();
	case BUTTON_ENTER_PRESS_SIGNAL:
		return Q_TRAN(uiMenuMaybeSettime);
	case BUTTON_UP_PRESS_SIGNAL:
		return Q_TRAN(uiShowMax);
	case BUTTON_DOWN_PRESS_SIGNAL:
		return Q_TRAN(uiShowMin);
	case CURRENT_TEMPERATURE_SIGNAL:
		me->ti = (int16_t) Q_PAR(me);
		show_temperature(me->ti);
	}
	return Q_SUPER(uiTop);
}


static int16_t get_calibrated_ti(struct UI *me)
{
	int16_t adjti;

	SERIALSTR("adj:");
	serial_send_int(me->ti);
	SERIALSTR(":");
	/* If the temperature value is outside the BSP range, leave it
	   there. */
	if ((LOWTI == me->ti) || (HIGHTI == me->ti)) {
		adjti = me->ti;
	} else {
		adjti = me->ti + me->cal;
		serial_send_int(adjti);
		/* If the calibration moved the value outside the
		   allowed range, indicate that. */
		if (adjti < MINTI) {
			adjti = LOWTI;
		} else if (adjti > MAXTI) {
			adjti = HIGHTI;
		}
	}
	SERIALSTR("\r\n");
	return adjti;
}
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

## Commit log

2013-09-30 First working MSP430 program.
    Flashes the LED on the Olimex MSP430-449STK2 board. Yay!
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2013-10-04 Correct the name of the BSP file.
    [bsp-449STK2.c]
2013-10-05 Put the MCU in a low power mode when QP is idle.
    We use LPM3 when the CPU is not required. LPM4 cannot be used because
    that shuts down the Basic Timer 1 clock, which is required to wake up
    again.
    The role of the LED has changed. It now is an indication that the CPU
    is awake. We turn the LED off when we go into low power mode, and
    turn it back on at the start of any interrupt handlers.
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2013-10-10 Use the MCU's internal temperature sensor.
    We display the hots and colds temperature every second second, and
    turn on all segments in the other seconds.
2013-10-11 Read the temperature every two seconds.
    Remove the state where we turn on all the segments, and read the
    temperature only every two seconds. This gives an indication of how
    much power will be consumed in real use.
2013-10-13 Add serial_drain(), mainly for QP-nano assertions.
    On assertion, we stop everything, then do the morse flashing. This
    means that we can miss the most recent serial data, as interrupts get
    turned off.
    So add serial_drain() to wait for everything to leave the serial port,
    so we can arrange to see all the output.
2013-10-13 Stop jumping quickly between temperatures.
    The ADC's LSB can sometimes appear unstable, and "jitter" back and
    forth by one LSB. If it happens to jitter over a temperature
    boundary, our temperature can jitter a whole degree each reading. So
    add some hysteresis in the temperature reading to prevent this.
    A single LSB of hysteresis (so the ADC reading has to move by two LSB
    for us to register a change) seems to be enough.
    [bsp-449STK2.c]
2013-10-14 Increase the temperature range and make calculations clearer.
    The temperature range is now -30 to +70 (50 Colds to 50 Hots), so it
    can be put essentially anywhere people will go in Australia.
    Some of the temperature calculations were not very clear, mainly
    to do with working out the index into the array of strings that
    indicate the temperature.
    To ensure we avoid overflow in the temperature calculations, all the
    values from the table of ADC to temperature and onwards are now
    int16_t instead of int8_t.
    [bsp-449STK2.c]
2013-10-16 Display the temperature directly, in degrees C.
    The display now shows temperature in increments of 0.5C, and updates
    more often than it does in the normal mode. This is the beginnings of
    the future calibration mode.
    In the calibration mode, the display in degrees C will only happen
    when the user is adjusting the temperature.
2013-10-16 Enter calibration mode when a switch is pressed.
    No calibration is done yet. We just change modes so we display
    degrees C while the switch is pressed.
2013-10-16 Implement the calibration mode.
    Calibration is done by holding down the first button. The display
    shows temperature in degrees C and the offset. (The temperature is
    shown as after the offset is applied.) Simultaneously pressing a
    second button increases the offset, and a third button decreases the
    offset. Releasing the first button returns to displaying hots and
    colds.
    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
2013-10-19 Slow down the temperature updates to conserver power.
    The temperature update uses a fair bit of power, as it has to run the
    ADC and then update the display. So to conserve power, we do these
    things:
    - Read the temperature every ten seconds, instead of every two.
    - Only update the display if the temperature has changed. This
    doesn't affect the current used by the display, but means that the
    CPU does less unnecessary work.
    [bsp-449STK2.c]
2013-10-19 Make the flashing LED optional.
    Add the LED indication with:
    make LED=yes
2013-10-20 Fix an error in timer periods.
    There was an error in the code that masked the timer period selection
    bits, that left bit 1 always high. This meant we could never select a
    Basic Timer 1 period less than fCLK2/8.
    Also, leave in the code that raises P2.0 whenever the CPU is awake,
    and lowers it when we enter low power mode.
    [bsp-449STK2.c]
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2013-10-21 Remove a delay that was accidentally left in the ADC code.
    We now wait for the ADC reference to stabilise with a timer event. It
    was a 17ms delay, so not insignificant.
    [bsp-449STK2.c]
2013-10-21 Measure temperature with a MCP9700A.
    The MCP9700A is an external temperature device in a TO-92 package. We
    want this package so we measure air temperature, not PCB temperature.
    The device is powered from a port pin (P6.1), with an RC power supply
    filter as recommended in its datasheet. It produces an analogue
    output, which we sense on pin A0 (P6.0). It produces zero degrees C
    at 500mV, and a slope of 10mV per degree. Its accuracy is typically
    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
2013-11-11 Change QP-nano to version 5.1.1.
    QP-nano 5.1.1 has a feature that we need - multiple timer sources. We
    can have several timers with different rates, and they send different
    signals. So in the future we can have a stable clock for an RTC, and
    a short period clock that is only turned on during temperature
    measurement or when the UI is busy.
2013-11-12 Use two different timers so we don't reset the RTC timer.
    Use a second timer when a fast timer tick is required, and leave Basic
    Timer 1 alone.
    Previously we have been using one timer (Basic Timer 1) to give us
    both the slow timer ticks (when we are paused and not doing much) and
    the fast timer ticks (when we are measuring temperature, or doing
    calibration.) Every time we change between clock rates, the Basic
    Timer module is restarted.
    But Basic Timer 1 will be used for the RTC, so we don't want to ever
    restart it.
    [bsp-449STK2.c]
2013-11-12 Show a clock on the LCD.
    This is a very basic RTC. There is no way to set the time or to
    adjust for clock drift.
    We use the clock digits at the top right of the SBLCDA2 display (or
    on the equivalent Olimex LCD-449STK2 display on the MSP430-449STK2
    development board.)
    We toggle the colon every two seconds to show life.
2013-11-13 Add a button state machine.
    We send events from the fast timer ISR to a button state machine,
    which decides how long buttons have been held down and whether to send
    button events to the (minimal) UI.
    The UI will be able to become more complicated with better button
    handling in place.
    The new button state machine does a fair bit of work on every tick,
    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
2013-11-14 Make a greater separation between time keeping and UI.
    Move the display of time into the UI, so that the RTC has to ask the
    UI to display time for it. This will make time setting easier.
    There is a cost: every two seconds we do a trip through QP-nano to get
    the signal and parameter into the UI. Previously we could short
    circuit this and flash the colon in the RTC, but now we have to get
    the UI to do that.
    [ui.c]
2013-11-18 Make QActive_post() and QActive_postISR() into tracing macros.
    In some stages of development, we are overrunning one event queue or
    other. The assertion in qfn.c is too generic to tell us exactly where
    in _our_ code this is happening, so do an event queue check before
    calling the QP-nano code that puts the event in the queue. Then we
    can tell exactly which part of our code is at fault.
    If the run time cost of this turns out to be too high, they can be
    made into conditional macros themselves.
    [bsp-449STK2.c]
2013-11-18 Make serial output faster.
    Serial output at 9600 baud is a bit slow to keep up with some of the
    information we need to get out. So output at 115200 instead.
    This means that with serial turned on (make SERIAL=yes) the 1MHz SMCLK
    is always enabled, do don't leave serial turned on in a battery
    powered system.
2013-11-18 Adjust the calibration with a proper menu item.
    A press of button 1 (detected only every two seconds) moves the UI
    into a menu state. There are two menu entries "T CAL" for temperature
    calibration, and "EXIT" to return to the normal thermometer mode.
    There is a timeout bar display (currently simulated with the "units"
    display on the LCD-449STK2) that counts down until the user interface
    automatically returns to thermometer mode. The timeout is reset any
    time a button is pressed.
    Other menu items can be added relatively easily from here. The
    biggest one to come is time setting.
    We also make some changes to the buttons, as the previous button code
    appeared too slow and was definitely ove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
    [bsp-449STK2.c]
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2013-11-24 Remove graphical=0 from the new symbols.
    Having graphical=0 makes gnetlist ignore the symbols, and they never
    appear in the PCB. This is a minor bug in gnetlist, so work around
    it.
    While we're here, fix a typo in the MCP9700A description.
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2013-11-30 Preliminary circuit diagram.
    May require adjustment as the layout progresses, so we can get better
    pin placement.
    [hc.sch]
2013-12-03 Correct the footprint for the Jaycar RU6700 super capacitor.
    The dimensions for ElementArc in a .fp file are radius, not diameter.
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2013-12-04 Improve the Keystone 1020 battery holder footprint.
    - Add a '+' symbol for plarity.
    - Add an outline.
    - Make the pads slightly larger.
2013-12-23 Correct the LCD connections in the circuit.
    Make them match the connections on the MSP430-449STK2 board.
    The SBLCDA2 and LCD449STK have the same pinout, with the only
    difference being the function of the antenna segments on the SBLCDA2
    which map to the "umHF" segments on the LCD449STK2.
    [hc.sch]
2014-01-22 Add a 6x1 header component for pcb.
    This component is for the FTDI serial connection.
2014-01-22 First board layout.
    This is the board that was sent for fabricaction on 2013-01-22.
    Changes to the components:
    - Increased the size of the X1 pins to meet the minimum size for
    pcbzone. This also reduces the number of hole sizes by one.
    - Swapped the X1 pins.
    - Changed the SBLCDA2 (U2) pins from 6000 diameter and 6500 clearance,
    to 5000 diameter and 5500 clearance, so we can route tracks between
    them.
    These changes have not been fed back to the footprint files.
2014-01-25 Maintain the date as well as the time.
    The default starting date is 2014-03-07 (of course). But with the
    proposed hardware, the super capacitor should maintain power over
    battery changes and the data should never need setting.
    We maintain days of the month correctly, including leap years. We
    allow years from 2014 to 2399. The upper limit of the year means that
    we can assume that every fourth year is a leap year, and not worry
    about the fourth century exceptions.
    TODO: set the default starting time to the time of the ceremony.
    [ui.c]
2014-01-25 Allow time rate adjustment.
    The time rate adjustment is in seconds/day, with a range of +/-9. The
    adjustment is subtracted from the seconds count at the rollover of
    each day. So an adjustment of +5 means that the first minute of each
    day is five seconds shorter than normal.
    To figure out the adjustment, set the time one day and find the
    clock's offset from the real time at the same time the next day. If
    the clock loses time, the adjustment should be negative
    This may not be fine enough for a real clock, as one second per day is
    about six minutes per year.
    [bsp-449STK2.c, ui.c]
2014-01-30 Create a recorder active object to maintain temperatures.
    This moves the temperature measurement and recording out of the user
    interface.
    Previously this wasn't an issue as we only displayed the current
    temperature. But now that we intend keep a record of the day's
    maximum and minimum temperatures, we want these maintained even while
    the UI is otherwise busy.
    [bsp-449STK2.c]
2014-01-31 When returning from a UI action, show the temperature immediately.
    Previously, when the user has finished an action in the user interface
    and we return to the idle state that just shows the current
    temperature, we had to wait for a temperature event from the recorder
    before anything was displayed. This seemed like the UI was hanging.
    So fix that by showing the current temperature immediately if it's
    available.
    We show "???" if the temperature is not yet available.
    [ui.c]
2014-02-01 Display the highest and lowest 24 hour temperatures.
    The highest and lowest temperatures over the current and preceding 24
    hour recording periods are displayed when either the up or down button
    is pressed.
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2014-02-06 Make it work on the prototype hardware.
    Changes:
    - Set all unused pins to known values. This avoids unused pins draining
    current when they get spurious signals.
    - Slight change to the LED startup flash.
    - Display question mark values for out of range temperatures.
    - Make the morse flash work again.
    - Remove the button code from the Basic Timer 1 interrupt, and make the button
    check functions always return false. The real code for the real buttons will
    be added soon.
    [bsp-449STK2.c, ui.c]
2014-02-08 Use the buttons on the new hardware and run a faster BT1.
    Also, correct a series of silly errors in the macros that make the
    unused pins into low outputs. (I had eg SB(P1DIR,4) instead of the
    correct SB(P1DIR,BIT4).)
    The new hardware has buttons on different pins to the dev board.
    Also, we now run the Basic Timer 1 ISR at 32Hz instead of 0.5Hz. See
    the comment below about bounces.
    NOTE: We are only using buttons 1, 2, and 3 now. Button 4 (Cancel)
    will be added when we have code to handle it.
    The buttons are connected to:
    B1 - P1.3
    B2 - P1.2
    B3 - P1.1
    B4 - P1.0
    Yes, they're in reverse order. It was easier to route the signals
    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
    [bsp-449STK2.c, ui.c]
2014-02-09 Fix the temperature reading on the new hardware.
    [bsp-449STK2.c]
2014-02-10 Get the RTC to do time adjustments.
    Move time adjustment calculations out of the user interface, and into
    the real time clock. This simplifies the UI, which only gets told
    about time events and doesn't have to do any adjustments.
    The user can adjust the RTC rate in 1/4 second per day increments,
    between +9.75 and -9.75 seconds per day. The actual adjustment is
    done is 1/8 second steps, several times per day depending on the
    amount. The number of steps and the times that the steps happen are
    generated at compile time.
    The adjustment is the offset that the clock needs to have.
    - If the clock runs fast, the adjustment needs to be negative.
    - If the clock runs slow, the adjustment needs to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
    [bsp-449STK2.c]
2014-02-11 Create a better board.
    The core of the board wasn't changed, as it appears to work well.
    Things added to the circuit:
    - LED - look at the layout to decide which pin to use.
    - Power jumper (HEADER2_1).
    - Reset switch (Jaycar_SP0611).
    - Debouncing capacitors on the buttons.
    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
    [hc.sch]
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2014-02-15 Fix the initialisation code for unused IO pins.
    [bsp-449STK2.c]
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2014-02-15 Reset the seconds when the time is set.
    When the user presses the button to set the time, we now reset the
    seconds counter. Previously, the seconds counter could have been up
    to two seconds ahead of the set time, making that setting less
    accurate than we needed.
    [bsp-449STK2.c, ui.c]
2014-02-16 Add the ability to automatically check the time adjustment.
    When SERIAL=yes, the device will print the time every minute, in the
    form
    \r\nTIME=HHMM\r\n
    There is also a script that will read these times, work out the
    current offset, and print the time and offset. The script sorts
    through the other debugging output and only reacts to those lines.
    We can then leave the device running and the script running with its
    stdin from the serial port, and check for clock drift by examining the
    offsets.
2014-02-17 Fix a comment that should have been changed a couple of commits ago.
    The comment refers to the adjustment range, and still referred to
    +/-9.75 seconds instead of +/-20 seconds.
    I didn't change this comment to match the code in c446c60 "Make the
    time adjustment range wider".
2014-02-20 Design the front and back covers in LibreCAD.
    panels/front-panel.dxf and panels/back-panel.dxf are the designs that
    were sent for maunfacture.
    [back-panel.dxf, front-panel.dxf]
2014-02-21 Turn off the time display while displaying max and min.
    Parts of the max and min display look like a normal temperature
    display. To avoid this confusion (which has caught me out
    occasionally) turn off the time part so the whole display looks
    significantly different.
    [ui.c]
2014-02-22 Use the cancel button.
    Also move swap the enter and cancel buttons as on the second board.
    Because we now have a cancel button, there is no need for the exit
    state in the menu system.
    [bsp-449STK2.c, ui.c]
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2014-02-25 Avoid spurious button presses when entering or leaving the UI.
    When entering or leaving the UI, we tell the buttons state machine to
    wait for all buttons to be up before proceeding. Because the buttons
    are quite bouncy, we can see all buttons up immediately followed by a
    button press possibly a couple of times. So make the buttons UI wait
    longer - a number of ISRs with no buttons down, in succession - before
    proceeding.
    When the fast timers are not running, the BSP has the same issue, so
    get the timer ISR to also count ticks with all buttons up.
    [bsp-449STK2.c]
2014-02-25 Use the MSP430 internal crystal oscillator capacitors.
    Using the internal capacitors for the low frequency oscillator
    eliminates the need for two external capacitors.
    [bsp-449STK2.c]
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2014-02-27 Use a better internal oscillator capacitor value.
    It seems that the highest value (18pF) gives the most accurate clock.
    [bsp-449STK2.c]
2014-03-01 Fix the temperature calibration menu mode.
    Previously, we sent signals from the ADC ISR to only the recorder, and
    never to any other AO. So when the ui was in temperature calibration
    mode, it never saw the replies. Fix that.
    This also includes a bit of code intended for the unimplemented
    battery monitor - specifically the channel enum that selects the
    desired ADC channel, and the VCC_CHANNEL value.
    [bsp-449STK2.c, ui.c]
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2014-03-04 Fix the temperature calibration mode.
    [ui.c]
2014-03-04 Fix the startup message to match the proper name.
    [ui.c]
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2014-03-05 Fix random ADC wait assertions.
    These were caused by the UI exiting the calibration mode while it had
    the ADC locked, and not releasing the ADC.
    While the UI is in the states that have the ADC locked, we defer the
    events that cause us to exit, and handle those when we go back to the
    calibration mode's pause state. We can actually only defer one event,
    and if there are multiple events that get deferred, only the last is
    remembered. But that should be sufficient as the user will not be
    able to tell the difference between
    - "I pressed the button but I just missed the end of the menu timeout
    period", and
    - "I pressed the button but the menu timeout period happened just
    after and overwro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
    [ui.c]
2014-03-17 On assertion, save info in memory for later display.
    The assertion string and number (normally module and line number) are
    saved in RAM, in a place that doesn't get initialised on startup.
    They are displayed by a "secret" menu entry -- get to the bottom entry
    ("ADJTIME"), then press down seven more times to display the assertion
    string on the main display, and the number on the time display. The
    number is limited to four digits, but since it's meant to be a line
    number that shouldn't be a real limitation.
    As an added secret, press down 37 more times while displaying the last
    assertion to create a new one!
    [bsp-449STK2.c]
